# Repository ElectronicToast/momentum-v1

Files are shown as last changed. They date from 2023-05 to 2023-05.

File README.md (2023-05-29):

# momentum-v1
An elegant circuit board for a more civilized age

<p align="center">
  <b>Star Wars: Revenge of the Ditch<br>
     26 May 2023</b><br>
</p>

## Description
This is a simple prop controller designed for a Ditch Day stack at Caltech. [Ditch Day](https://www.pasadenanow.com/main/ditch-day-on-friday-caltech-seniors-create-a-whirlwind-of-fun-and-challenges) is a tradition where undergraduate seniors design elaborate themed experiences, called "stacks", for the enjoyment of younger students on a date kept secret until the last minute.

This Ditch Day stack featured custom lightsabers with WS2812 LED lighting and motion-reactive sound effects. This repository contains the hardware and firmware used in the lightsabers.

## Hardware
- Raspberry Pi Pico
- MT-3608 boost converter module, permitting flexible power input (designed for 2S D cell batteries)
- 1x WS2812 LED output with 5V buffer
- PAM8302 2.5W Class-D audio amplifier
- 2x pushbutton input with RC debouncing 
- Socket for MPU-6050 IMU

Fabrication output is generated using [KiKit](https://github.com/yaqwsx/KiKit), targeting the JLCPCB assembly service. It is recommended to order panels to lower costs; 10 panels of 4 were fabricated for Ditch Day with a target of 20 production units.

- [Schematic](https://github.com/ElectronicToast/momentum-v1/blob/main/board/doc/momentum.pdf)
- [Interactive BOM](http://htmlpreview.github.io/?https://github.com/ElectronicToast/momentum-v1/blob/main/board/doc/ibom.html)

## Firmware
The code is written using the Raspberry Pi Pico C SDK and has been tested to build and run properly on Ubuntu 22.04 LTS (with the Pico SDK installed per Raspberry Pi's instructions) and Windows (using the [Windows installer](https://github.com/raspberrypi/pico-setup-windows)).  

## Assembly Notes
- The MPU-6050 is intended to fit over the MT-3608 boost converter. Header pins can be soldered to the MPU-6050, then soldered into the row of pins on the PCB. Take care to respect the orientation.
- The LED output pads are not in the same order as a typical WS2812 strip (board errata).
- There is no reverse polarity protection, though the MT-3608 may be tolerant of reverse polarity.

## Usage
`uf2` binaries as used for Ditch Day are provided in `firmware/bin/`. The nomenclature `44k1r2` refers to audio at 44.1 kHz sampling rate and with every sample repeated twice (so PWM clock frequency of 44.1 kHz * 2 * 256).

To modify the code,
1. Install the Pico C SDK, including `pico-extras`. You might also install Visual Studio Code and the relevant extensions (CMake, C/C++, etc.) if you prefer an IDE.
2. Modify definitions in `config.h` as appropriate for e.g. flash-on-clash animations
3. From `firmware/src/`, `mkdir build`
4. `cd build`
5. `cmake ..`
6. `make` (or `ninja` if using the Windows SDK installer)

Upload the code as with any RP2040 binary using the USB bootloader (plug in USB while holding down BOOTSEL on the Pico, and drag-and-drop the `.uf2` file into the `RPI-P2` 'flash drive' that appears.

## Customizing sounds
A converter utility Python script is provided, which takes a set of WAV files (one `poweron.wav` 'ignition' sound, one `poweroff.wav` deactivation sound, one 'hum.wav' idle sound, and any number of `clash0.wav` `clash1.wav`... clash sounds and `swing0.wav` `swing1.wav`... swing sounds) and creates a C header file with `uint8_t` arrays and suitable definitions. 

If you would like to use your own sounds, convert them to WAV, run the Python script on them, and include the generated `.h` file in `speaker.c`.

## Future Improvements
- Single custom PCB with more flash (RP2040 supports up to 16 MB versus Pico stock 2 MB)
- SD card support
- Motion detection uses interrupt features of MPU-6050, which use only the accelerometer. Clash and swing sensing can be improved.
- Due to budget, there is no physical power switch, and WS2812s have high quiescent current. Add a physical power switch or a MOSFET.
- Design for Li-Ion power versus 2S D-cell (chosen for safety)

<p align="center">
  <b>Go to bed frosh, Ditch Day is Tomorrow!<br>
</p>

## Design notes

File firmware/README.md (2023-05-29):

# Firmware

The project under `src/` uses the Pico C SDK and includes `.vscode` configurations for compiling/debugging via VSCode. 

## Debugging

The `launch.json` files are configured for use with [pico_debug](https://github.com/essele/pico_debug) by essele, as descrived [here](https://forums.raspberrypi.com/viewtopic.php?t=337284). This is much faster than a stock picoprobe interfacing with OpenOCD's GDB server. The firmware can be flashed onto any picoprobe equivalent target.

Since this is functionally similar to the Black Magic Probe, the launch configuration is named `Pico Magic`.

You may of course use a stock picoprobe, but be sure to change the `launch.json`.

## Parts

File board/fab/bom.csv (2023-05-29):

Comment | Designator | Footprint | LCSC
10k | R3,R8,R9 | Resistor_SMD:R_0805_2012Metric_Pad1.20x1.40mm_HandSolder | C17414
47uF | C7 | Capacitor_SMD:C_0805_2012Metric_Pad1.18x1.45mm_HandSolder | C16780
100 | R1,R2,R10,R11 | Resistor_SMD:R_0805_2012Metric_Pad1.20x1.40mm_HandSolder | C17408
0.1uF | C1,C6,C9,C10 | Capacitor_SMD:C_0805_2012Metric_Pad1.18x1.45mm_HandSolder | C28233
220 | R12 | Resistor_SMD:R_0805_2012Metric_Pad1.20x1.40mm_HandSolder | C17557
1uF | C2,C3,C4 | Capacitor_SMD:C_0805_2012Metric_Pad1.18x1.45mm_HandSolder | C28323
PAM8302AAD | U2 | Package_SO:SOIC-8_3.9x4.9mm_P1.27mm | C112137
SN74LV1T34DBVR | U1 | Package_TO_SOT_SMD:SOT-23-5_HandSoldering | C100024
1.8k | R13 | Resistor_SMD:R_0805_2012Metric_Pad1.20x1.40mm_HandSolder | C17398
10k | RV1 | Potentiometer_SMD:Potentiometer_Bourns_TC33X_Vertical | C719176
10uF | C5 | Capacitor_SMD:C_0805_2012Metric_Pad1.18x1.45mm_HandSolder | C15850

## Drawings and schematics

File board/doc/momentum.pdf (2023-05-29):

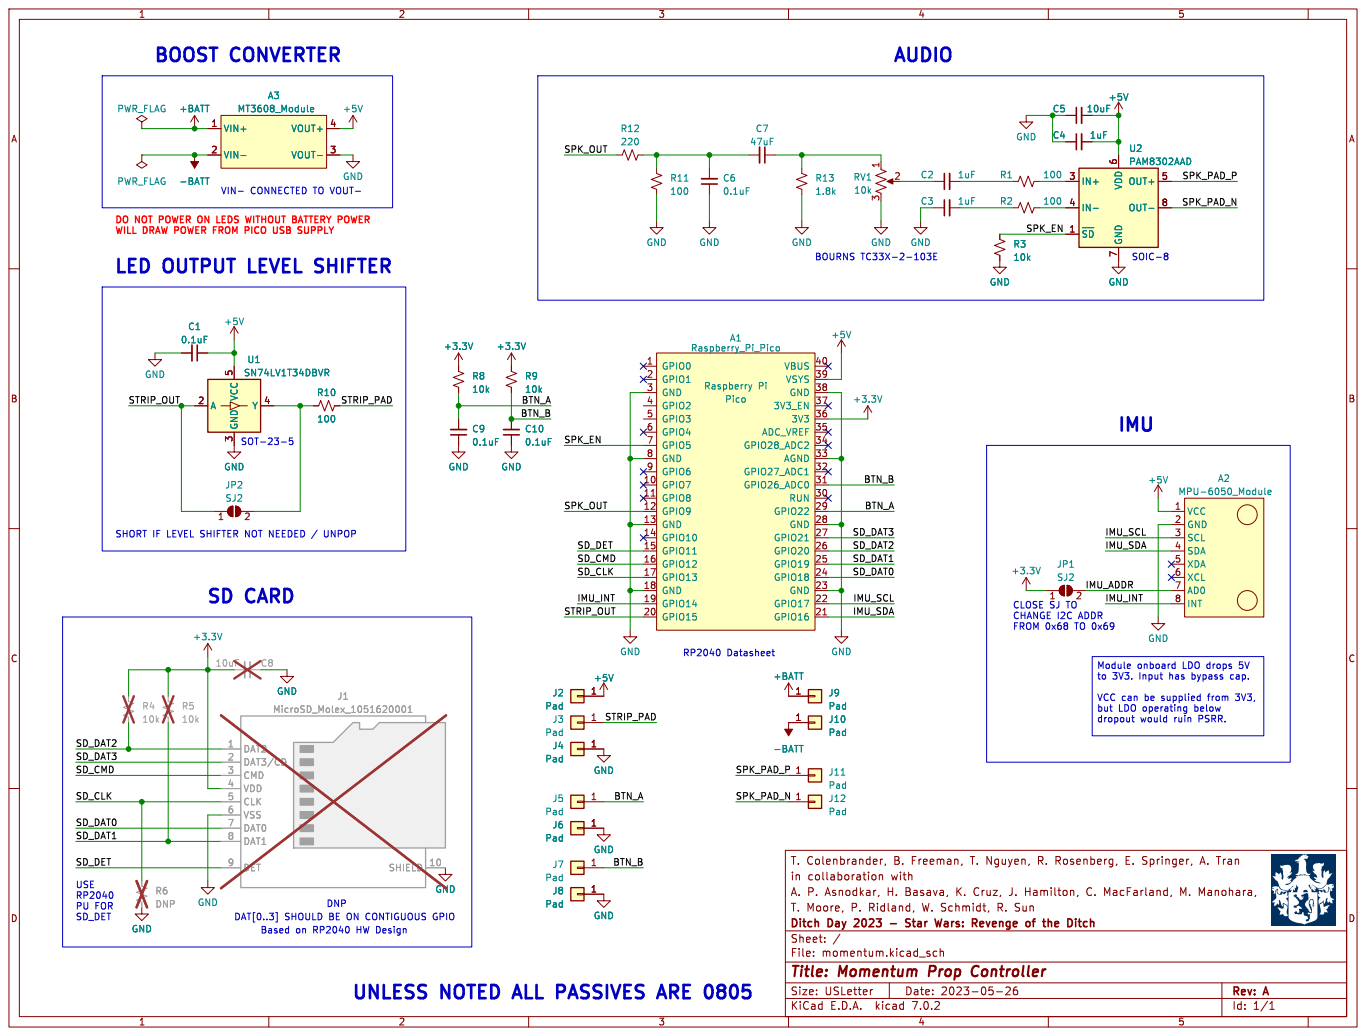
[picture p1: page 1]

BOOST CONVERTER
DO NOT POWER ON LEDS WITHOUT BATTERY POWER WILL DRAW POWER FROM PICO USB SUPPLY USE RP2040 PU FOR

10k PWR_FLAG
IMU_SCL SD_DAT1 VIN- CONNECTED TO VOUT- LED OUTPUT LEVEL SHIFTER

dropout would ruin PSRR. C1

VCC 1 GND 2 SCL 3 SDA 4 XDA 5 XCL 6 AD0 7

SHORT IF LEVEL SHIFTER NOT NEEDED / UNPOP

Module onboard LDO drops 5V

Based on RP2040 HW Design (https://datasheets.raspberrypi.com/rp2040/hardware-design-with-rp2040.pdf) DNP UNLESS NOTED ALL PASSIVES ARE 0805

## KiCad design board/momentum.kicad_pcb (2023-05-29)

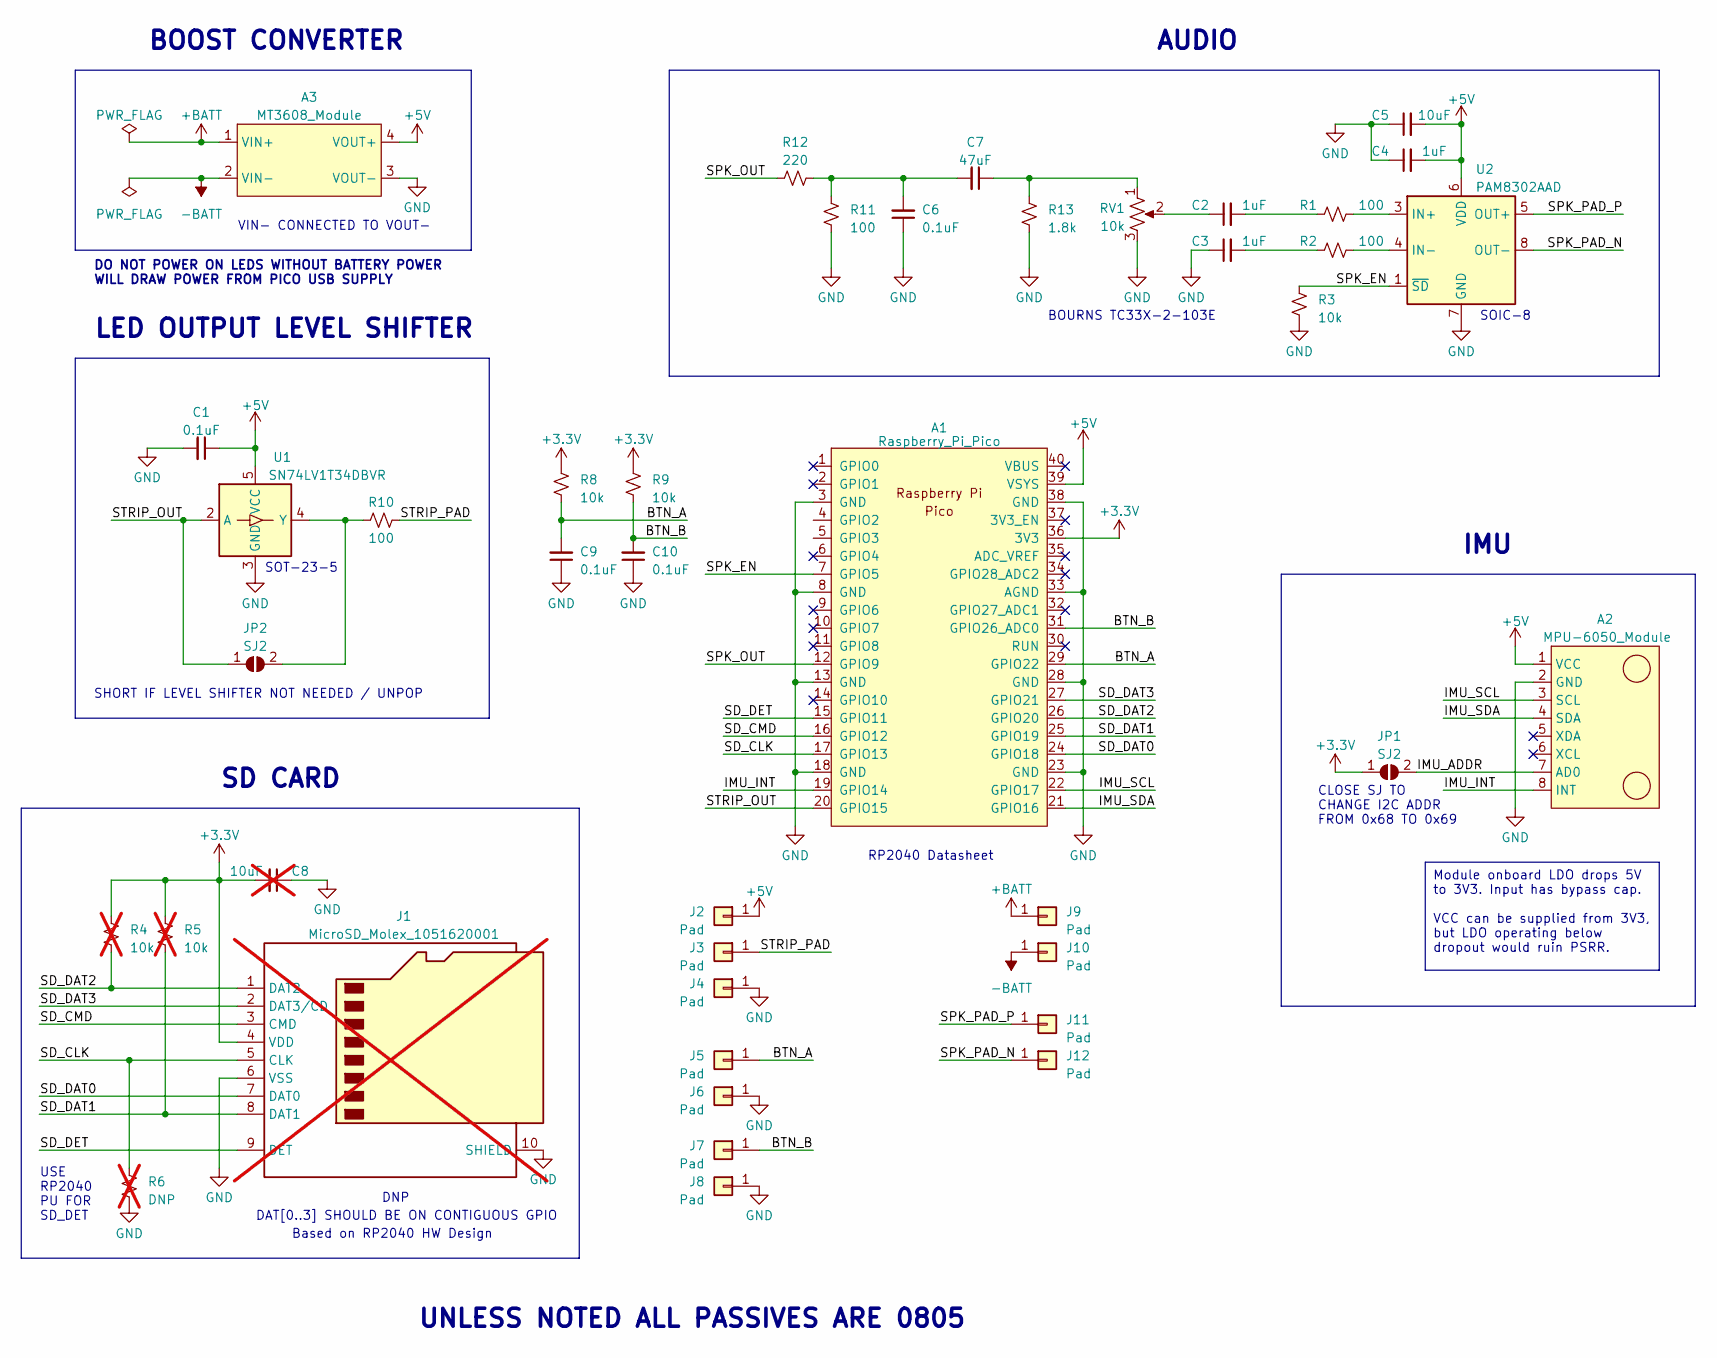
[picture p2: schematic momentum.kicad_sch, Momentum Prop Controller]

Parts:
A1: Raspberry_Pi_Pico; RPi_Pico_SMD_NoSWD_NoLabel; LCSC NA
A2: MPU-6050_Module; LCSC NA
A3: MT3608_Module; MT3608_Module_SMD; LCSC NA
C1, C6, C9, C10: 0.1uF; C_0805_2012Metric_Pad1.18x1.45mm_HandSolder; LCSC C28233
C2, C3, C4: 1uF; C_0805_2012Metric_Pad1.18x1.45mm_HandSolder; LCSC C28323
C5: 10uF; C_0805_2012Metric_Pad1.18x1.45mm_HandSolder; LCSC C15850
C7: 47uF; C_0805_2012Metric_Pad1.18x1.45mm_HandSolder; LCSC C16780
C8: 10uF; C_0805_2012Metric_Pad1.18x1.45mm_HandSolder_NoPaste; LCSC C15850; not fitted
J1: MicroSD_Molex_1051620001; MicroSD_Molex_1051620001_HandSoldering; LCSC NA; not fitted
J2, J3, J4, J5, J6, J7, J8, J9, J10, J11, J12: Pad; LCSC NA
JP1, JP2: SJ2; SolderJumper-2_P1.3mm_Open_Pad1.0x1.5mm; LCSC NA
R1, R2, R10, R11: 100; R_0805_2012Metric_Pad1.20x1.40mm_HandSolder; LCSC C17408
R3, R8, R9: 10k; R_0805_2012Metric_Pad1.20x1.40mm_HandSolder; LCSC C17414
R4, R5: 10k; R_0805_2012Metric_Pad1.20x1.40mm_HandSolder_NoPaste; JLCPCB_IGNORE Y; not fitted
R6: DNP; R_0805_2012Metric_Pad1.20x1.40mm_HandSolder_NoPaste; LCSC NA; not fitted
R12: 220; R_0805_2012Metric_Pad1.20x1.40mm_HandSolder; LCSC C17557
R13: 1.8k; R_0805_2012Metric_Pad1.20x1.40mm_HandSolder; LCSC C17398
RV1: 10k; Potentiometer_Bourns_TC33X_Vertical; LCSC C719176
U1: SN74LV1T34DBVR; SOT-23-5_HandSoldering; LCSC C100024
U2: PAM8302AAD; SOIC-8_3.9x4.9mm_P1.27mm; LCSC C112137

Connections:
+3.3V: A1.36 (3V3), C8.2, J1.4 (VDD), JP1.1 (A), R4.2, R5.2, R8.2, R9.2
+5V: A1.39 (VSYS), A2.1 (VCC), A3.4 (VOUT+), C1.1, C4.2, C5.2, J2.1, U1.5 (VCC), U2.6 (VDD)
+BATT: A3.1 (VIN+), J9.1
-BATT: A3.2 (VIN-), J10.1
/BTN_A: A1.29 (GPIO22), C9.2, J5.1, R8.1
/BTN_B: A1.31 (GPIO26_ADC0), C10.2, J7.1, R9.1
/IMU_ADDR: A2.7 (AD0), JP1.2 (B)
/IMU_INT: A1.19 (GPIO14), A2.8 (INT)
/IMU_SCL: A1.22 (GPIO17), A2.3 (SCL)
/IMU_SDA: A1.21 (GPIO16), A2.4 (SDA)
/SD_CLK: A1.17 (GPIO13), J1.5 (CLK), R6.2
/SD_CMD: A1.16 (GPIO12), J1.3 (CMD)
/SD_DAT0: A1.24 (GPIO18), J1.7 (DAT0)
/SD_DAT1: A1.25 (GPIO19), J1.8 (DAT1), R5.1
/SD_DAT2: A1.26 (GPIO20), J1.1 (DAT2), R4.1
/SD_DAT3: A1.27 (GPIO21), J1.2 (DAT3/CD)
/SD_DET: A1.15 (GPIO11), J1.9 (DET)
/SPK_EN: A1.7 (GPIO5), R3.2, U2.1 (~SD)
/SPK_OUT: A1.12 (GPIO9), R12.1
/SPK_PAD_N: J12.1, U2.8 (OUT-)
/SPK_PAD_P: J11.1, U2.5 (OUT+)
/STRIP_OUT: A1.20 (GPIO15), JP2.1 (A), U1.2 (A)
/STRIP_PAD: J3.1, R10.2
GND: A1.3 (GND), A1.8 (GND), A1.13 (GND), A1.18 (GND), A1.23 (GND), A1.28 (GND), A1.33 (AGND), A1.38 (GND), A2.2 (GND), A3.3 (VOUT-), C1.2, C3.1, C4.1, C5.1, C6.1, C8.1, C9.1, C10.1, J1.6 (VSS), J1.10 (SHIELD), J4.1, J6.1, J8.1, R3.1, R6.1, R11.2, R13.2, RV1.3, U1.3 (GND), U2.7 (GND)
unnamed: C2.1, RV1.2
unnamed: C2.2, R1.1
unnamed: C3.2, R2.1
unnamed: C6.2, C7.2, R11.1, R12.2
unnamed: C7.1, R13.1, RV1.1
unnamed: JP2.2 (B), R10.1, U1.4 (Y)
unnamed: R1.2, U2.3 (IN+)
unnamed: R2.2, U2.4 (IN-)

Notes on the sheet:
Module onboard LDO drops 5V to 3V3. Input has bypass cap. VCC can be supplied from 3V3, but LDO operating below dropout would ruin PSRR.
AUDIO
SOIC-8
DO NOT POWER ON LEDS WITHOUT BATTERY POWER WILL DRAW POWER FROM PICO USB SUPPLY
LED OUTPUT LEVEL SHIFTER
BOURNS TC33X-2-103E
SHORT IF LEVEL SHIFTER NOT NEEDED / UNPOP
VIN- CONNECTED TO VOUT-
Based on RP2040 HW Design
USE RP2040 PU FOR SD_DET
IMU
UNLESS NOTED ALL PASSIVES ARE 0805
DAT[0..3] SHOULD BE ON CONTIGUOUS GPIO
CLOSE SJ TO CHANGE I2C ADDR FROM 0x68 TO 0x69
RP2040 Datasheet
BOOST CONVERTER
SOT-23-5
DNP
SD CARD

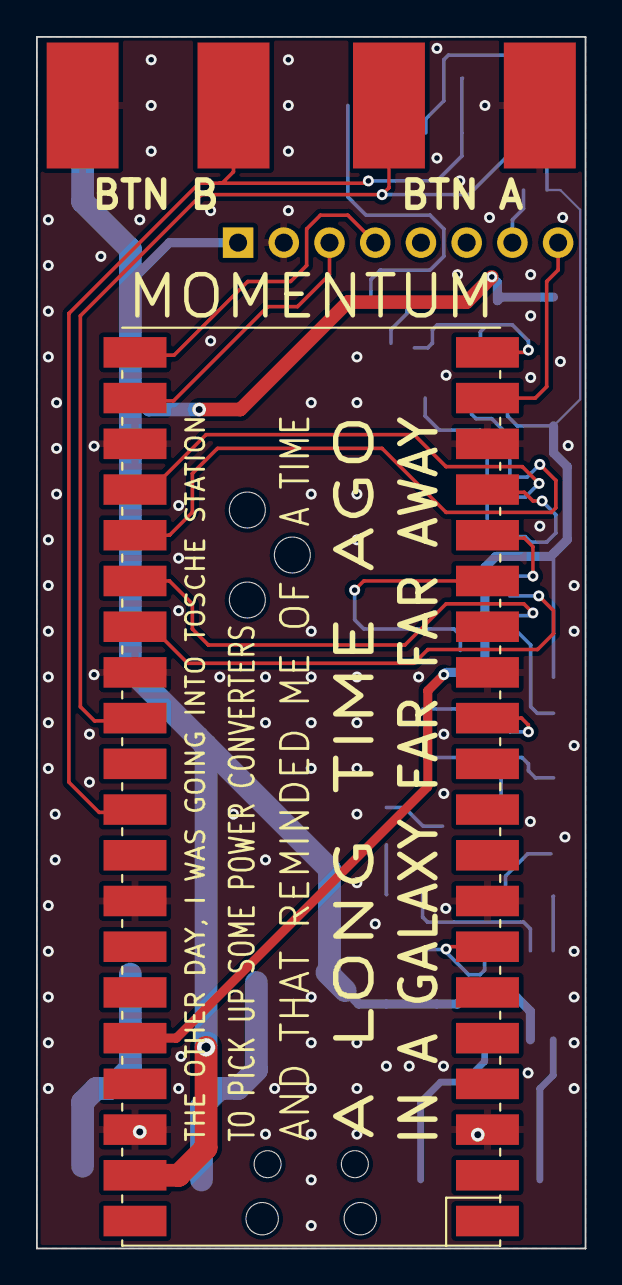
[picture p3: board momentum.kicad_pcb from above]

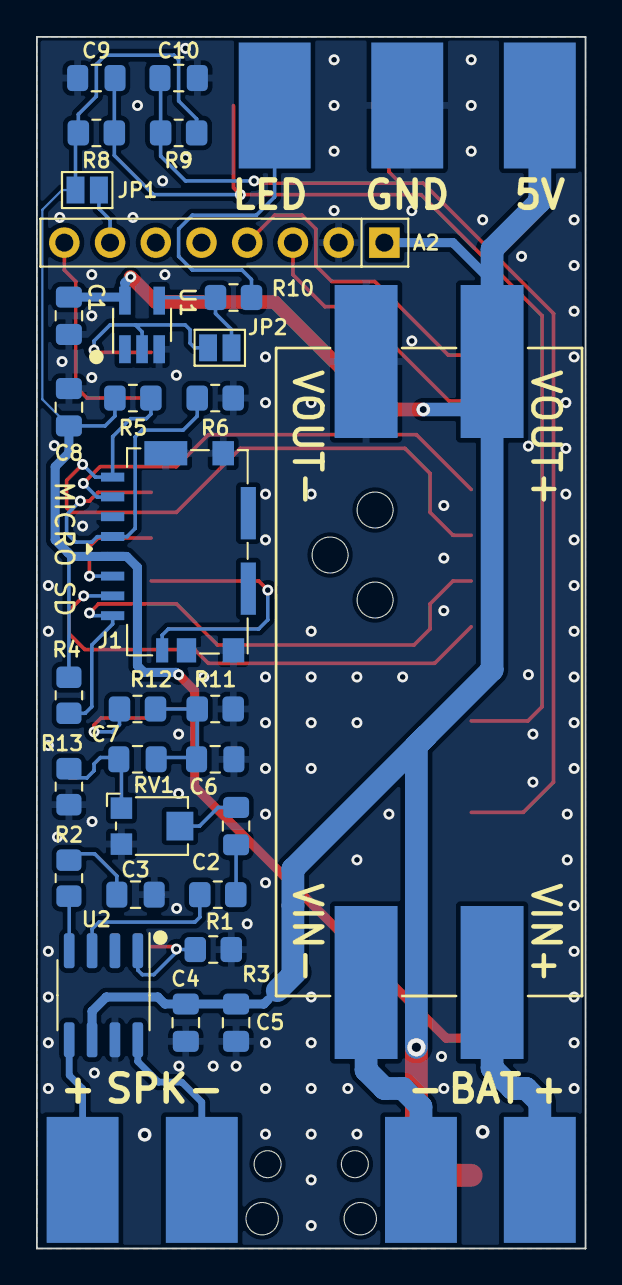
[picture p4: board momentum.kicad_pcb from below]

Board: 2 copper layers, 30.5 x 67.3 mm, 42 parts (37 on the bottom side), 32 nets.

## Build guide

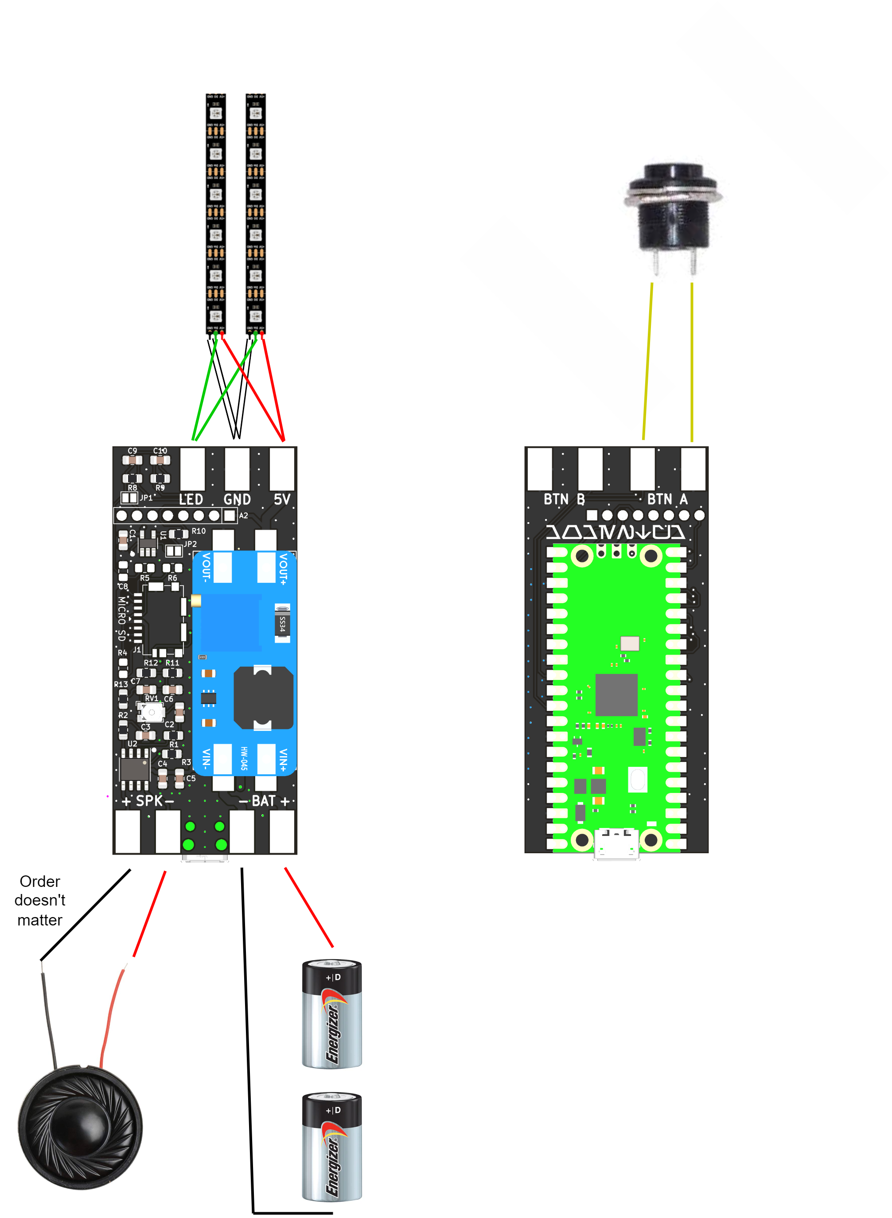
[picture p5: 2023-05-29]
board/doc/momentum_wiring_diagram.png

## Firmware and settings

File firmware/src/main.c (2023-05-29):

/**
 * @file main.c
 */

#include "sys.h"
#include "ledstrip.h"
#include "button.h"
#include "speaker.h"
#include "imu.h"

#include "pico/stdlib.h"
#include <stdio.h>
#include <string.h>
#include "config.h"

#include "hardware/rosc.h"


void setup_turnon() {
    // Uncomment if need to printf()
    //stdio_init_all();

    //gpio_init(PICO_DEFAULT_LED_PIN);
    //gpio_set_dir(PICO_DEFAULT_LED_PIN, GPIO_OUT);
    //gpio_put(PICO_DEFAULT_LED_PIN, 0);

    ledstrip_turn_on();

    // Hum sound starts playing automatically after power-on
    spk_play_turnon();

    #ifdef IMU_RESET_ON_EVENT
        // DO NOT USE
        imu_i2c_init();
        imu_reset();
        imu_configure_interrupt();
    #else
        // IMU needs to be stationary for some time before motion is detected
        #ifdef IMU_SLEEP
            imu_wake_up();
        #endif
    #endif

    // Kludge to stop motion detection / button presses during poweron tune.
    // Since poweron goes to hum immediately on DMA interrupt, events during
    // poweron are only processed after the first hum sound has played all the
    // way through.
    // Should be longer than poweron tune length
    sleep_ms(SYS_POWERON_DELAY);

    btn_clear_press();
    imu_clear_motion();
}


int main()
{
    // Sleep until first button press
    sys_init();
    sys_go_dormant();

    // Code resumes here after any button pressB

    // Pick random color here for possibly better randomness versus using the 
    // ROSC random bit function on startup
    #ifdef SABER_STARTUP_COLOR_RANDOM
        ledstrip_set_random_color();
    #endif
    setup_turnon();

    while (true) {
        if (imu_has_clash()) {
            spk_stop();
            spk_play_clash();
            #ifdef LEDSTRIP_FLASH_ON_CLASH
                ledstrip_flash();
            #endif
        }
        if (imu_has_swing()) {
            spk_stop();
            spk_play_swing();
        }

        // After a motion, resume playing hum sound repeatedly
        if (spk_is_done_playing()) {
            spk_play_hum_repeat();
        }

        // Long press and release - change the LED strip color
        if (btn_has_long_press()) {
            ledstrip_next_color();
            
            #ifdef IMU_RESET_ON_EVENT
                imu_i2c_init();
                imu_reset();
                imu_configure_interrupt();
            #endif
        }

        // Short press - turn off
        if (btn_has_short_press()) {
            spk_stop();
            spk_play_turnoff();
            ledstrip_turn_off();

            spk_wait_until_done_playing();
            spk_disable();
            #ifdef IMU_SLEEP
                imu_goto_sleep();
            #endif

            sys_go_dormant();
            
            // Code resumes here after any button press
            setup_turnon();
        }
    }
}

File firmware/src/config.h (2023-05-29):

/**
 * @file config.h
 * @brief System configuration definitions
 */

#ifndef CONFIG_H
#define CONFIG_H


// ------------------------------ OVERALL --------------------------------------
// Uncomment for dark side mode - only color is red, cannot change color
//#define SABER_DARK_SIDE

// Uncomment for deliberately slow power-on and power-off; works well with
// dark side
//#define SABER_POWERONOFF_SLOW

// Uncomment to pick a random color on startup. Only applicable to normal / 
// light side mode.
#define SABER_STARTUP_COLOR_RANDOM
// -----------------------------------------------------------------------------

// ------------------------------ SOUNDS ---------------------------------------
// Select which `tunes_xxx.h` file to use. These files should have a poweron,
// poweroff, hum, and multiple swing/clash sounds comprising a length and a 
// uint8_t array. Use the audio conversion script to generate `tunes_xxx.h` 
// files from a set of WAV files.
//
// If none are defined, the original sounds used in development will be used,
// which have only a single swing/clash sound.
//
// This does not impact how the main loop handles playing different swing/clash
// sounds for different motions (if there is any capability of doing such),
// but the definition can be used in the main loop too to configure this.
// Uncomment only one!
//#define TUNES_USE_EP4                   // Dark side suitable
#define TUNES_USE_OBS                   // Normal-sounding
//#define TUNES_USE_CLASSIC               // Also normal-sounding, hum too quiet
//#define TUNES_USE_OBS_CLASSICPWR          // Classic poweron/off, obs others
// Nothing uncommented -- use original poweron and poweroff but with obs sounds

// Playback frquency of the audio samples
// Uncomment only one!
//#define TUNE_22KHZ
//#define TUNE_8KHZ
#define TUNE_44KHZ
// -----------------------------------------------------------------------------

// ----------------------------- MOTION ----------------------------------------
// In case of unstable power supply that causes the IMU to act up, reset it 
// on poweron or color change button press?
//
// NOT WORKING, WAS NOT EVEN DEFINED IN MAIN
//#define IMU_RESET_ON_EVENT   

// Sleep the IMU when saber off
#define IMU_SLEEP

// Threshold for clash detection, in the default accelerometer units of the IMU
// (MPU-6050 motion detection interrupt)
#define IMU_THRESH_CLASH        48
// Duration for clash detection, in milliseconds
#define IMU_N_CLASH_DUR         20

// Threshold for swing detection, in the default accelerometer units of the IMU
// MPU-6050 zero-motion detection interrupt
#define IMU_THRESH_SWING        144
// Duration for swing detection, in units of 64 ms
#define IMU_N_SWING_DUR         8
// -----------------------------------------------------------------------------

// ----------------------------- LED STRIP -------------------------------------
// Number of WS2812B LEDs in the strip.
#define N_LEDSTRIP_LEDS         25

// Flash LED strip on a clash motion?
//#define LEDSTRIP_FLASH_ON_CLASH

// Number of milliseconds it takes for one LED to turn on / off during strip
// turning on or off
#ifdef SABER_POWERONOFF_SLOW
    #define N_LEDSTRIP_TURN_ON_MS   30
    #define N_LEDSTRIP_TURN_OFF_MS  30
#else 
    #define N_LEDSTRIP_TURN_ON_MS   30
    #define N_LEDSTRIP_TURN_OFF_MS  30
#endif

// Maximum number of flashes to do when a clash is detected, as a power of 2
#define N_LEDSTRIP_FLASH_MAX            12

// Minimum duration of flash, in units of power of 2 milliseconds
#define N_LEDSTRIP_FLASH_MIN_MS         6

// Maximum duration of flash
#define N_LEDSTRIP_FLASH_MAX_MS         12

// Minimum delay between flashes
#define N_LEDSTRIP_FLASH_DELAY_MIN_MS   16

// Maximum delay between flashes
#define N_LEDSTRIP_FLASH_DELAY_MAX_MS   32
// -----------------------------------------------------------------------------

// ---------------------------- SYSTEM -----------------------------------------
#define SYS_POWERON_DELAY       1600        // ms, should > poweron tune length

#define SYS_CLK_FREQ_KHZ        27000 // 108000    // 27000

#define SPK_PWM_COUNT_TOP       255         // 8-bit audio, wrap at 8-bit top

// At 44.1 kHz PWM frequency and 4 repetitions
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

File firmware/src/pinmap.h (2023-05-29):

/**
 * @file pinmap.h
 * @brief Raspberry Pi Pico pinout
 */


#ifndef _PINMAP_H_
#define _PINMAP_H_


// WS2812B LED strip
#define PIN_LEDSTRIP            15

// PAM8302 audio amplifier PWM output
#define PIN_SPK_PWM             9

// PAM8302 active high enable
#define PIN_SPK_EN              5     

// Pushbutton (Button A on board)
#define PIN_BTN                 22

// IMU
#define PIN_IMU_SDA             16
#define PIN_IMU_SCL             17
#define PIN_IMU_INT             14


#endif /* _PINMAP_H_ */
